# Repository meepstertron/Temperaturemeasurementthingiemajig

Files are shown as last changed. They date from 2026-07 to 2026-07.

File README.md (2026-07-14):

# Temperaturemeasurementthingimajig

That was a mouthful!

This is one of my first fully designed and hopefully made pcbs! :D

basically this is a small sensor node based on the readily availible CH32V003 which is a low cost (~20 cents!) risc-v MCU. it features a feature rich IO (well for 0.2usd it is). I am using the SHT4x chip to actually capture the environmental readings, because it is both accurate and fairly cost effective.

## Why should you care?

Honestly... You probably shouldnt, but for those who do want to know why: the whole node is open source meaning it can be re-mixed, re-branded and changed to your hearts content maybe even slap your logo or a silly cat on the silkscreen, it is also very cheap. running off a cr2032 and only costing about 3usd per node! Now compare that to the shelly series of Humid+Temp nodes...
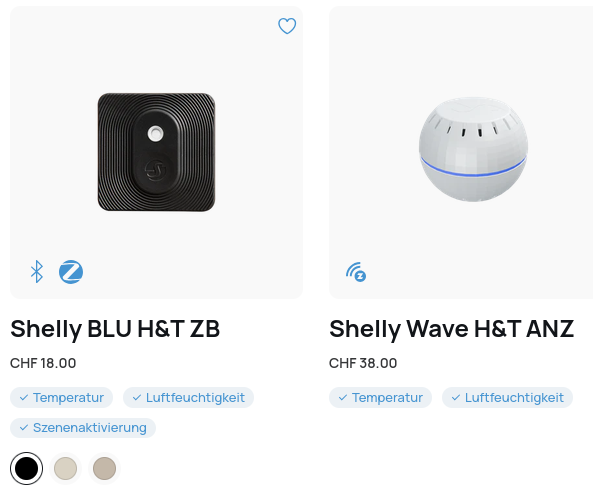
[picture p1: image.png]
image of two shelly products


## How is it so cheap??

I got it down to a nice value because i didnt use a expensive MCU like the ESP32 series (even though they are pretty effective in cost if you want wifi) but instead a cheaper and more bare bones MCU, since my project just didnt need it! a simple ASK/OOK transmitter instead of a costly variable or even wifi chip brought it down a lot as well. (we're talking cents but who cares)

## Bill of materials! (yall gotta foot the bill on this one :P /satire)
| Quantity | Component / Description | Package / Size | Estimated Cost (USD)
| :---: | :--- | :--- | :--- |
| **1x** | CR2032 Coin Cell Battery Holder | Through-Hole | 0.13 |
| **1x** | WCH CH32V003F4P6 Microcontroller | TSSOP-20 | 0.28 |
| **1x** | CMT2119A RF Transmitter | SOT-23-6 | 0.58 |
| **1x** | SHT4x Temperature & Humidity Sensor | DFN-4 | 0.95 |
| **1x** | 26MHz Crystal | SMD 3225 | 0.07 |
| **1x** | 868MHz Spring Antenna | Helical Spring | 0.23 |
| **1x** | Any color LED | 0805 | 0.02 |
| **2x** | 10k Ohm Resistor | 0805 | 0.004 |
| **1x** | 1k Ohm Resistor | 0805 | 0.004 |
| **1x** | 8.2nH Inductor | 0805 | 0.04 |
| **1x** | 100nH Inductor | 0805 | 0.04 |
| **1x** | 47uF Capacitor | 0805 | 0.22 |
| **2x** | 100nF (0.1uF) Capacitor | 0805 | 0.034 |
| **1x** | 82pF Capacitor | 0805 | 0.018 |
| **1x** | 3.9pF Capacitor | 0805 | 0.015 |

## AI...

I want to be as transparent as i can. I did use AI to help me scout components like the SHT40 instead of the AHT20 i was familiar with. i also used it for my rf, it called out my shitty meander (which i calculated as a microstrip, oops) which i then replaced with a more easier to work with coil antenna.
However i do not feel as if i used ai to a higher degree than 20% since i still did all of the design work, i wired up the schematic, i read the datasheets and i eventually designed the pcb.

## What programs were used
 - KiCad
 - Onshape

## Images :D
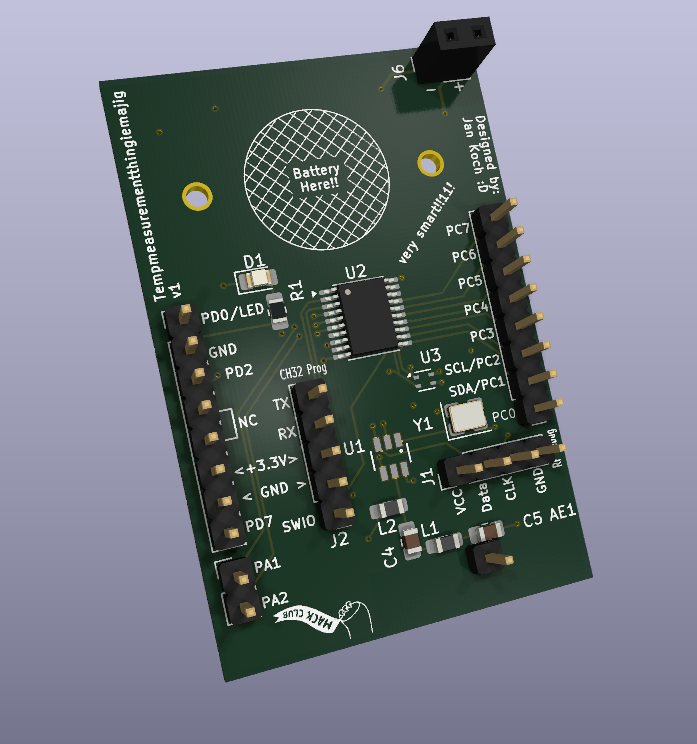
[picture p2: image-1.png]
Rendered front side of pcb showing components and silkscreen

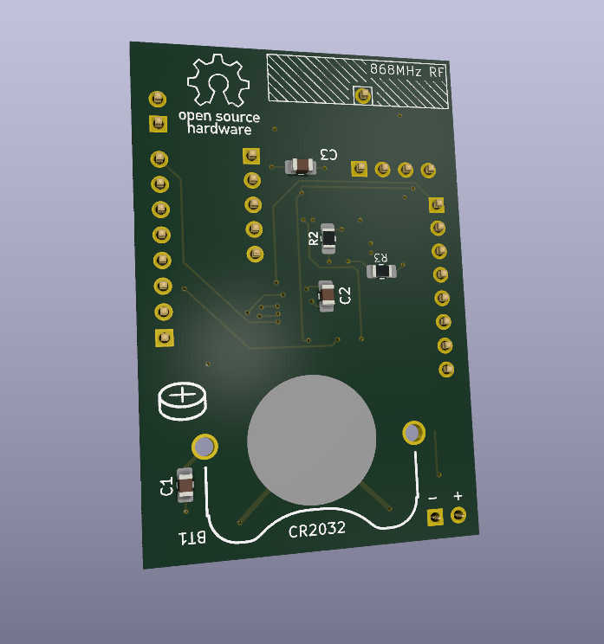
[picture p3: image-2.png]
Rendered back side of pcb showing components and silkscreen

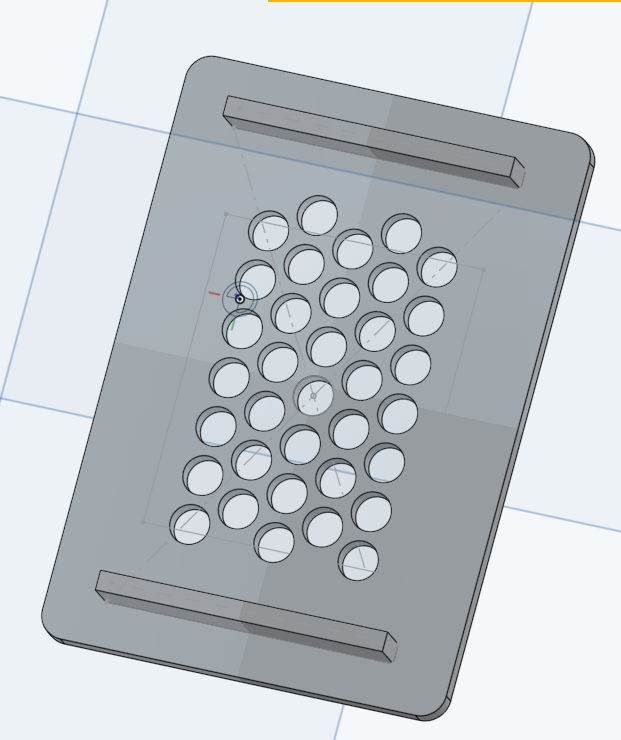
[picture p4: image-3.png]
3d mockup of case lid

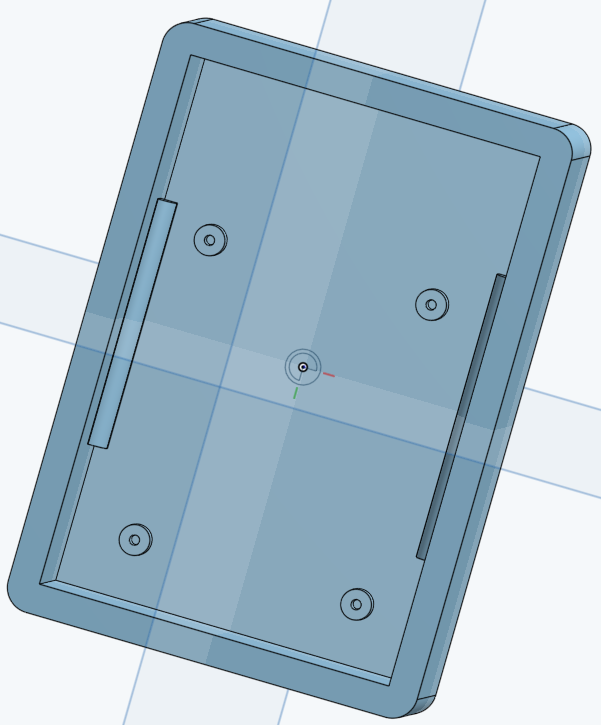
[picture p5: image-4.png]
3d mockup of case body

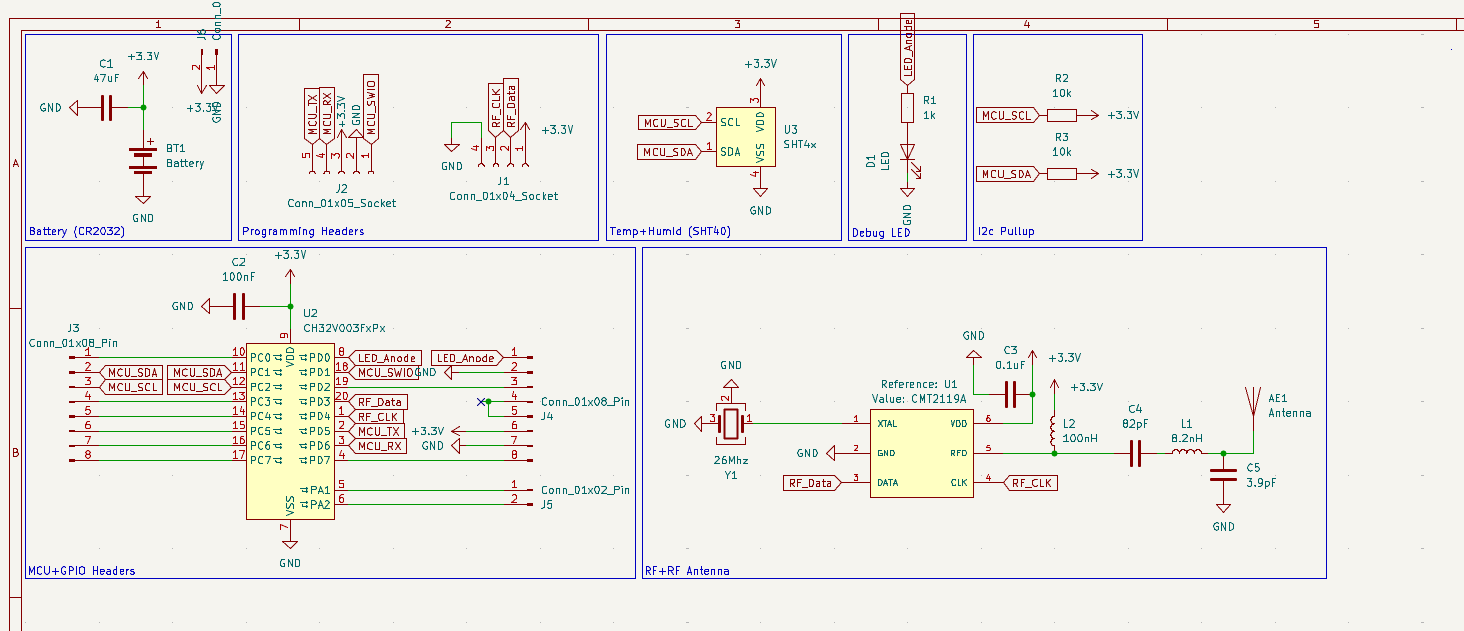
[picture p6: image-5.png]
Schematic

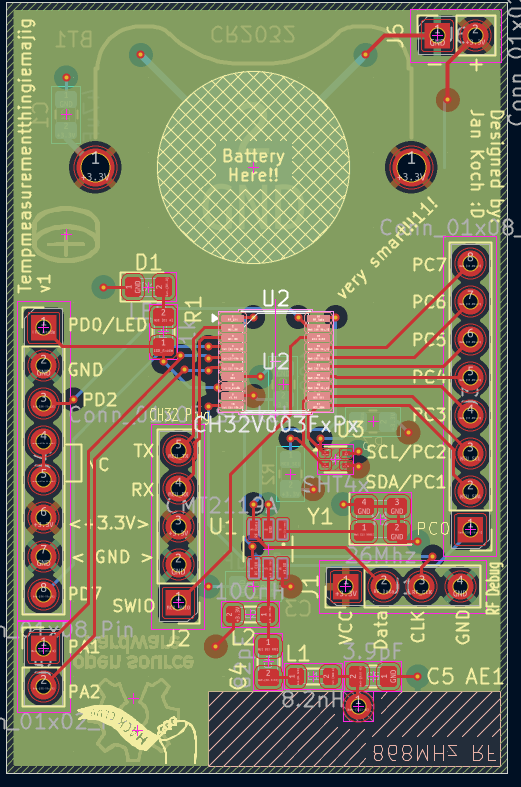
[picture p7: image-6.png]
2d PCB with all layers visible, Front in focus

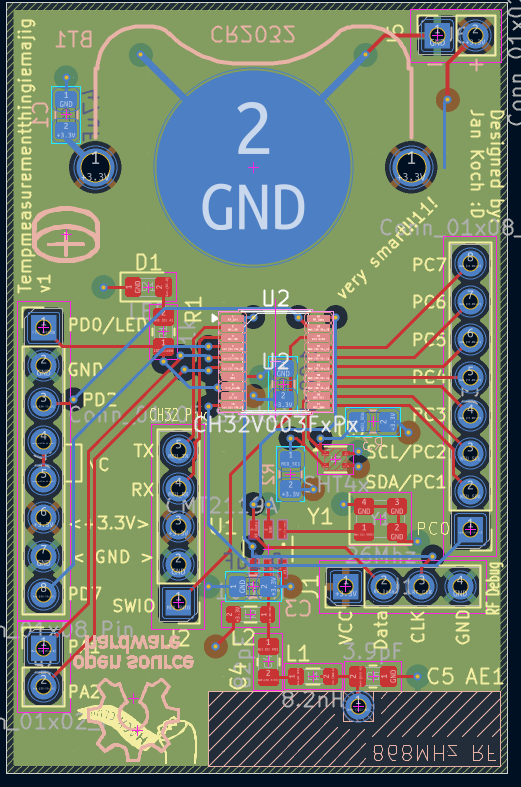
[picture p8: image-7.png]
2d PCB with all layers visible, Back in focus

## Hackclub? 

This is a submission to hackclub's forge! Hackclub is a cool charity yall should go check them out!

## Contact me or sum

Email: jan.koch@hexagonical.ch

orrr:

@meepstertron on the hackclub slack!

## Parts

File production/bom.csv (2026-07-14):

Designator | Footprint | Quantity | Value | LCSC Part #
BT1 | BAT-TH_MY-2032-06 | 1 | Battery | C964823
C1 | 0805 | 1 | 47uF
C2 | 0805 | 1 | 100nF
C3 | 0805 | 1 | 0.1uF
C4 | 0805 | 1 | 82pF
C5 | 0805 | 1 | 3.9pF
D1 | 0805 | 1 | LED
J1 | PinHeader_1x04_P2.54mm_Vertical | 1 | Conn_01x04_Socket
J2 | PinHeader_1x05_P2.54mm_Vertical | 1 | Conn_01x05_Socket
J3, J4 | PinHeader_1x08_P2.54mm_Vertical | 2 | Conn_01x08_Pin
J5 | PinHeader_1x02_P2.54mm_Vertical | 1 | Conn_01x02_Pin
J6 | PinSocket_1x02_P2.54mm_Vertical | 1 | Conn_01x02_Pin
L1 | 0805 | 1 | 8.2nH
L2 | 0805 | 1 | 100nH
R1 | 0805 | 1 | 1k
R2, R3 | 0805 | 2 | 10k
U1 | SOT23-6 | 1 | CMT2119A
U2 | TSSOP-20_4.4x6.5mm_P0.65mm | 1 | CH32V003FxPx
U3 | Sensirion_DFN-4_1.5x1.5mm_P0.8mm_SHT4x_NoCentralPad | 1 | SHT4x
Y1 | Crystal_SMD_3225-4Pin_3.2x2.5mm | 1 | 26Mhz
AN1 | Antenna_Helical_Spring | 1 | 868MHz

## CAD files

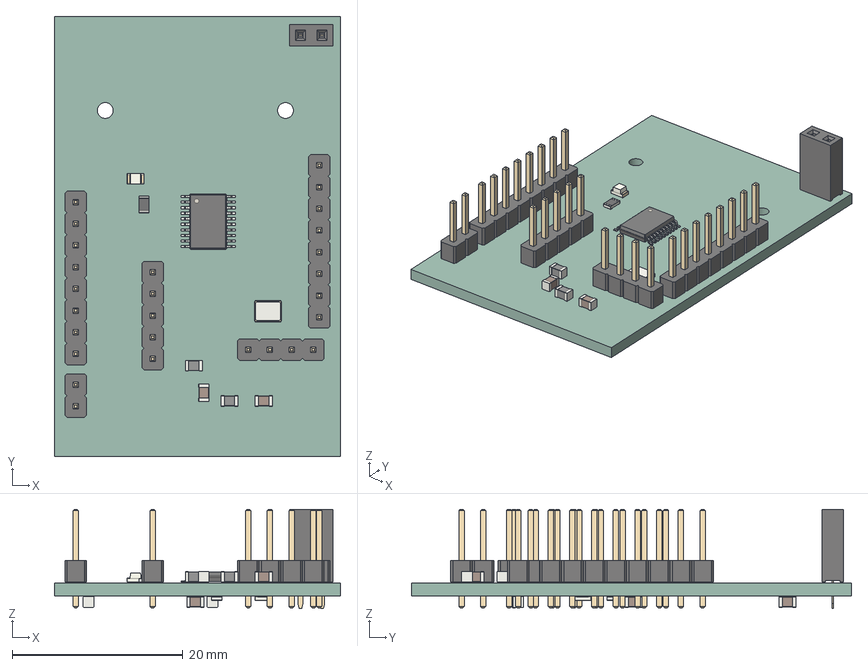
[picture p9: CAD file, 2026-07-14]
_restore_backup_2026-07-14T16-18-22-128/.step
33.5 x 51.5 x 11.6 mm
PinHeader_1x02_P254mm_Vertical
PinHeader_1x08_P254mm_Vertical x 2
R_0805_2012Metric x 3
TSSOP-20_4.4x6.5mm_P0.65mm
C_0805_2012Metric x 5
Crystal_SMD_3225-4Pin_3.2x2.5mm
L_0805_2012Metric x 2
PinHeader_1x04_P254mm_Vertical
LED_0805_2012Metric
PinSocket_1x02_P2.54mm_Vertical
PinHeader_1x05_P254mm_Vertical
Tempmeasurementthingiemajig-unsaved-export-E9l15V_PCB

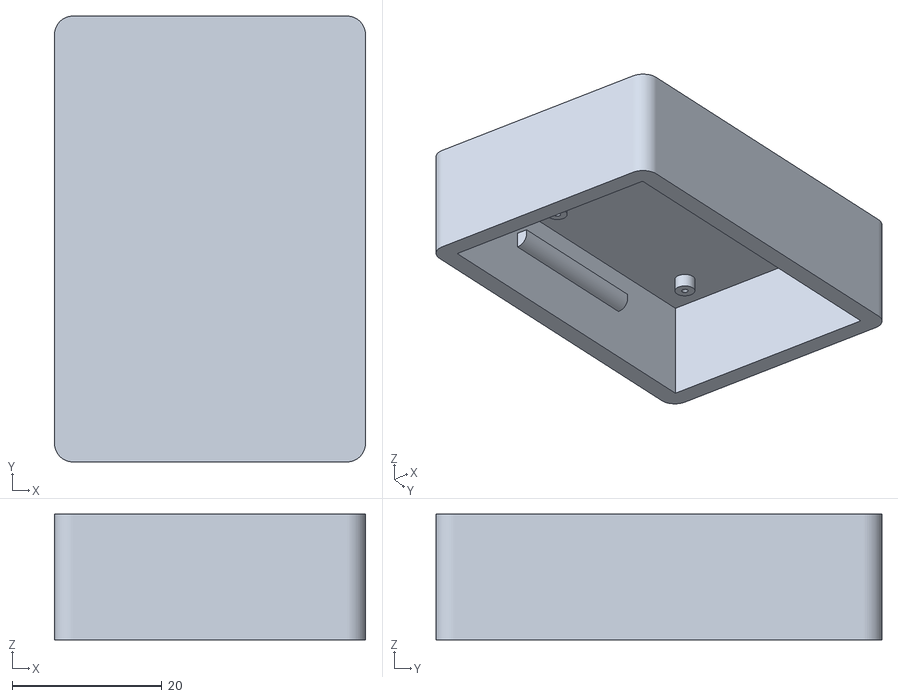
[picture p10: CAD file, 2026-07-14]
case_bottom.stl
41.5 x 59.5 x 16.8

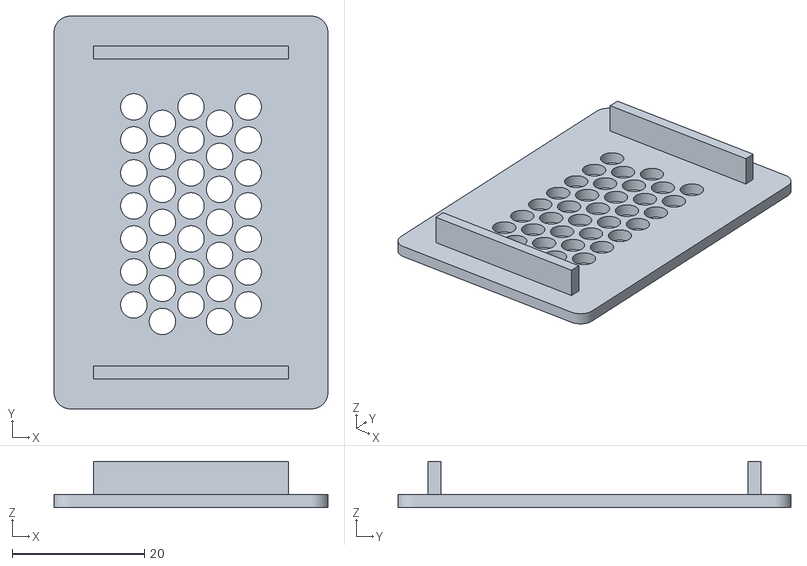
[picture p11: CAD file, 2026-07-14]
case_top.stl
41.5 x 59.5 x 7.00

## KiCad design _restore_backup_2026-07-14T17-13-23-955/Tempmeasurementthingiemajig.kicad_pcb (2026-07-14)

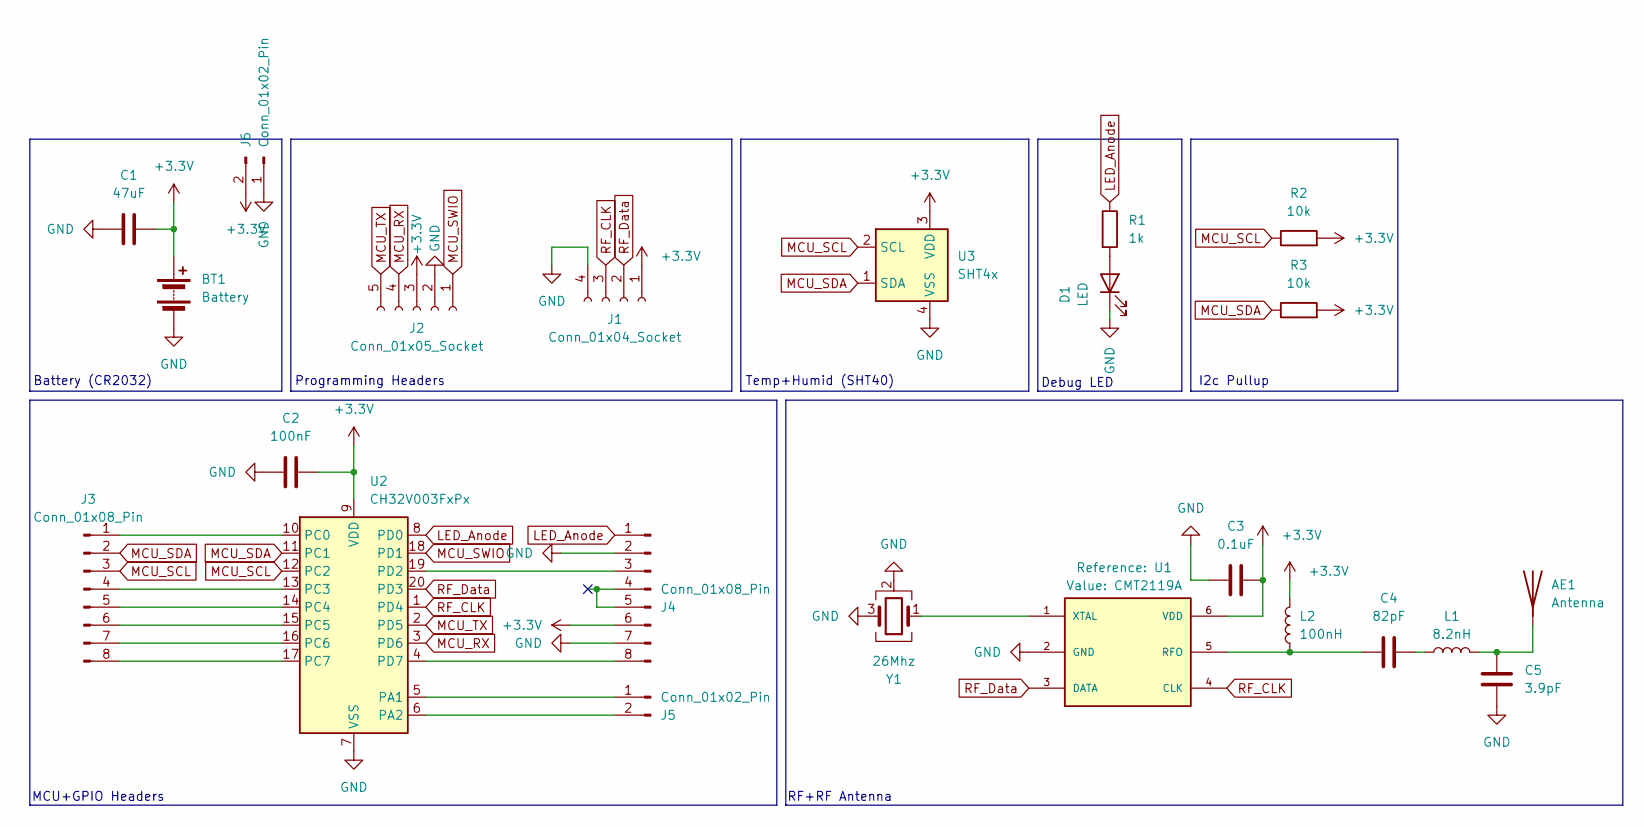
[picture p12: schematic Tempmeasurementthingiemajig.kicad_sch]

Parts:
AE1: Antenna
BT1: Battery; BAT-TH_MY-2032-06
C1: 47uF; C_0805_2012Metric_Pad1.18x1.45mm_HandSolder
C2: 100nF; C_0805_2012Metric_Pad1.18x1.45mm_HandSolder
C3: 0.1uF; C_0805_2012Metric_Pad1.18x1.45mm_HandSolder
C4: 82pF; C_0805_2012Metric_Pad1.18x1.45mm_HandSolder
C5: 3.9pF; C_0805_2012Metric_Pad1.18x1.45mm_HandSolder
D1: LED; LED_0805_2012Metric_Pad1.15x1.40mm_HandSolder
J1: Conn_01x04_Socket; PinHeader_1x04_P2.54mm_Vertical
J2: Conn_01x05_Socket; PinHeader_1x05_P2.54mm_Vertical
J3, J4: Conn_01x08_Pin; PinHeader_1x08_P2.54mm_Vertical
J5: Conn_01x02_Pin; PinHeader_1x02_P2.54mm_Vertical
J6: Conn_01x02_Pin; PinSocket_1x02_P2.54mm_Vertical
L1: 8.2nH; L_0805_2012Metric_Pad1.05x1.20mm_HandSolder
L2: 100nH; L_0805_2012Metric_Pad1.05x1.20mm_HandSolder
R1: 1k; R_0805_2012Metric_Pad1.20x1.40mm_HandSolder
R2, R3: 10k; R_0805_2012Metric_Pad1.20x1.40mm_HandSolder
U1: CMT2119A; SOT23-6
U2: CH32V003FxPx; TSSOP-20_4.4x6.5mm_P0.65mm
U3: SHT4x; Sensirion_DFN-4_1.5x1.5mm_P0.8mm_SHT4x_NoCentralPad
Y1: 26Mhz; Crystal_SMD_3225-4Pin_3.2x2.5mm

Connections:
+3.3V: BT1.1 (+), C1.2, C2.2, C3.2, J1.1, J2.3, J4.6, J6.2, L2.2, R2.2, R3.2, U1.6 (VDD), U2.9 (VDD), U3.3 (VDD)
GND: BT1.2 (-), C1.1, C2.1, C3.1, C5.1, D1.1 (K), J1.4, J2.2, J4.2, J4.7, J6.1, U1.2 (GND), U2.7 (VSS), U3.4 (VSS), Y1.2 (G), Y1.3, Y1.4 (G)
LED_Anode: J4.1, R1.1, U2.8 (PD0)
MCU_RX: J2.4, U2.3 (PD6)
MCU_SCL: J3.3, R2.1, U2.12 (PC2), U3.2 (SCL)
MCU_SDA: J3.2, R3.1, U2.11 (PC1), U3.1 (SDA)
MCU_SWIO: J2.1, U2.18 (PD1)
MCU_TX: J2.5, U2.2 (PD5)
unnamed: AE1.1, C5.2, L1.2
unnamed: C4.2, L1.1
unnamed: D1.2 (A), R1.2
unnamed: J3.1, U2.10 (PC0)
unnamed: J3.4, U2.13 (PC3)
unnamed: J3.5, U2.14 (PC4)
unnamed: J3.6, U2.15 (PC5)
unnamed: J3.7, U2.16 (PC6)
unnamed: J3.8, U2.17 (PC7)
unnamed: J4.3, U2.19 (PD2)
unnamed: J4.8, U2.4 (PD7)
unnamed: J5.1, U2.5 (PA1)
unnamed: J5.2, U2.6 (PA2)
unnamed: C4.1, L2.1, U1.5 (RFO)
unnamed: U1.1 (XTAL), Y1.1
RF_CLK: J1.3, U1.4 (CLK), U2.1 (PD4)
RF_Data: J1.2, U1.3 (DATA), U2.20 (PD3)

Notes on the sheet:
I2c Pullup
Programming Headers
RF+RF Antenna
MCU+GPIO Headers
Temp+Humid (SHT40)
Debug LED
Battery (CR2032)

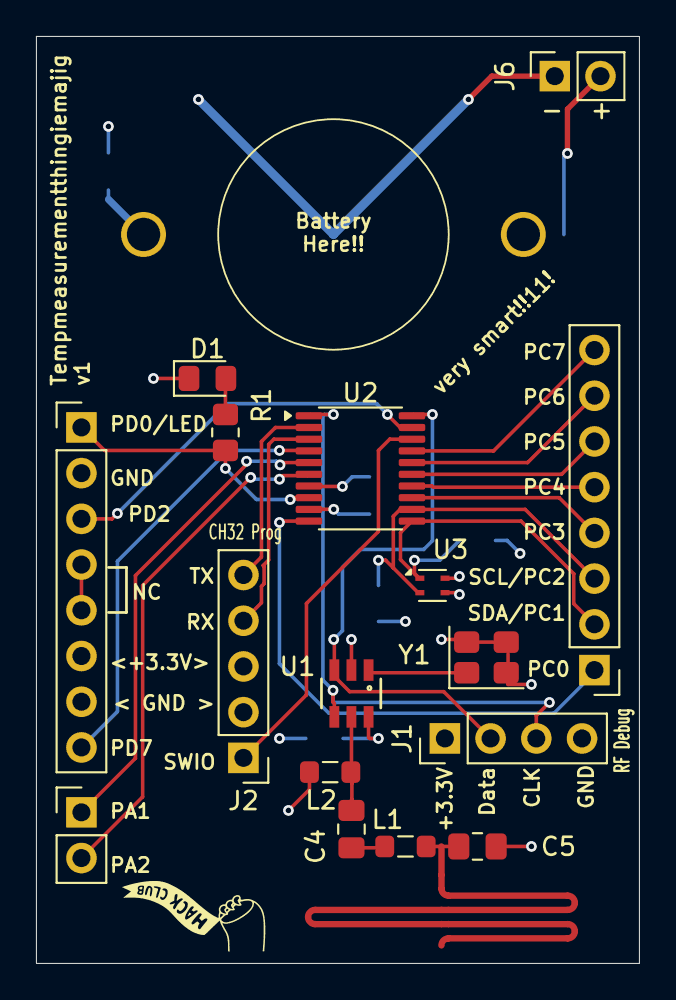
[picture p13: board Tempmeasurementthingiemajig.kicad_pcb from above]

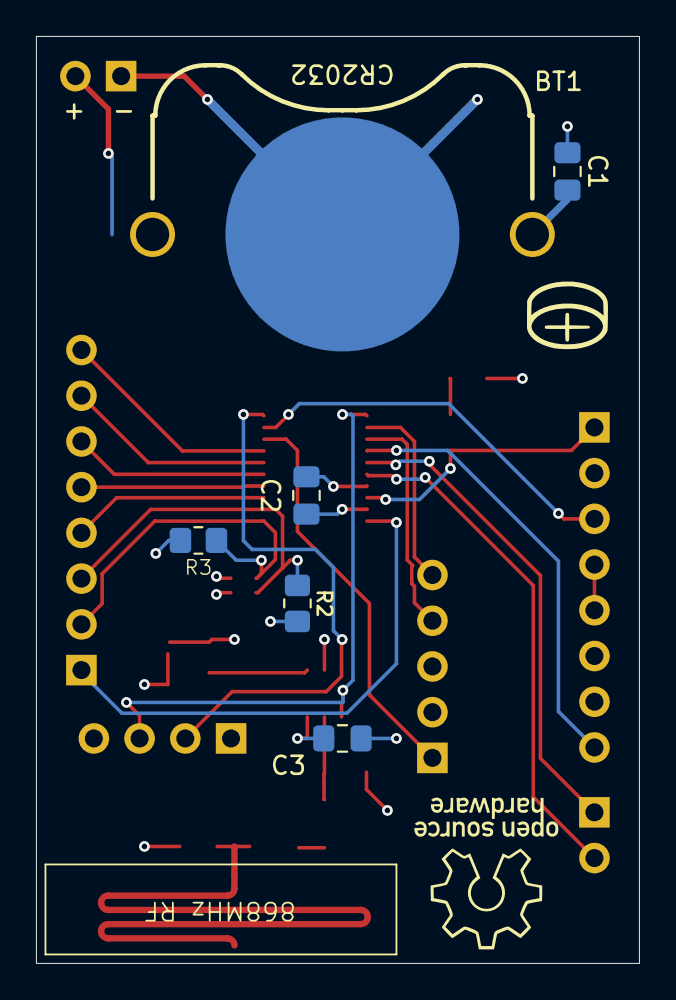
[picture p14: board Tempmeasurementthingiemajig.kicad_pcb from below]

Board: 4 copper layers, 33.5 x 51.5 mm, 22 parts (6 on the bottom side), 25 nets.

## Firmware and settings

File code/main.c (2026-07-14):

#include "ch32fun.h"
#include <stdio.h>

int main() {
    // Initialize system
    SystemInit();


    Delay_Ms(2000); // uh idk so i dont mess up my chip

    RCC->APB1PCENR

    // allow for deep sleep mode
    PWR->CTLR |= PWR_CTLR_PDDS;
    PFIC->SCTLR |= PFIC_SCTLR_SLEEPDEEP;

    while(1) {
        __WFE();
    }

}

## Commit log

2026-07-14 Worked on the pcb and exported it as gerbers+3d files
    [.step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]
2026-07-14 Worked on the initial code and fixed up the board a bit :)
    [main.c]
2026-07-14 Added the Case STLs
    [case_bottom.stl, case_top.stl]
2026-07-14 added the antenna to the bom, also added the BOM to the readme
    [bom.csv]
